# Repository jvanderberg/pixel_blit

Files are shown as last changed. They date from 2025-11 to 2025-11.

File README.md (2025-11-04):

# pixel_blit

A  32-channel addressable LED controller based on the Raspberry Pi RP2350B microcontroller.

## Overview

The pixel_blit is designed for controlling large-scale addressable LED installations. It features LVDS networking for daisy-chaining multiple controllers across long cable runs, making it ideal for large lighting installations.

## Key Specifications

- **Microcontroller**: Raspberry Pi RP2350B (QFN-80)
  - Dual Cortex-M33 cores @ 150 MHz
  - 8 PIO state machines for precise LED timing
  - USB High Speed (480 Mbps)

- **Output Channels**: 32 independent LED string outputs
  - 47Ω series resistors on all outputs
  - 3.3V to 5V level shifting
  - Screw terminal connections (3.5mm pitch)

- **Memory**:
  - 16MB QSPI Flash (W25Q128JVSIQTR)
  - MicroSD card slot for pattern storage

- **Power Management**:
  - 12V input via terminal blocks
  - TPS63070 buck-boost converter (12V → 5V, 2A)
  - ME6217C33 LDO regulator (5V → 3.3V, 300mA)

- **Networking**:
  - LVDS daisy-chaining via RJ45 connectors
  - 4-channel differential signaling (DSLVDS1047/1048)
  - 100Ω termination resistors
  - Supports long cable runs

- **User Interface**:
  - MicroSD card slot
  - 4 tactile buttons + 1 reset button
  - 4-position DIP switch
  - I2C display interface

## Board Details

- **PCB Size**: 175.5mm × 122.0mm
- **Layers**: 4-layer stackup (Signal/GND/Power/Signal)
- **Components**: 192 total (all SMT, single-sided assembly)
- **Connectors**:
  - 32× DB301V 3.5mm screw terminals (LED outputs)
  - 4× power input terminals (12V)
  - 2× RJ45 (LVDS networking)
  - 1× USB-C

## Architecture

### Signal Path
```
RP2350B GPIO (3.3V)
  → SN74LVC8T245 Level Shifter (4× 8-channel)
  → 47Ω Series Resistor
  → Screw Terminal
  → LED String
```

### Power Distribution
```
12V Input
  → TPS63070 Buck-Boost → 5V (LED outputs, level shifters)
  → ME6217C33 LDO → 3.3V (MCU, flash, LVDS)
  → RP2350B Internal → 1.1V
```

### Network Topology
```
[Controller 1] —RJ45→ Cat5/Cat6 —RJ45→ [Controller 2] —RJ45→ ...
```
LVDS differential signaling enables daisy-chaining multiple boards with deterministic latency and excellent noise immunity.

## Component Summary

| Type | Count | Examples |
|---|---|---|
| Resistors | 65 | 47Ω series resistors, 100Ω LVDS termination |
| Capacitors | 45 | Decoupling and power filtering |
| ICs | 50+ | MCU, flash, level shifters, LVDS transceivers |
| Terminal Blocks | 36 | 32 LED outputs + 4 power inputs |
| Level Shifters | 4 | SN74LVC8T245PWR (8-channel each) |
| Switches/Buttons | 5 | Tactile buttons + DIP switch |
| LVDS Transceivers | 2 | Driver and receiver pair |

## Features

- 32 independent addressable LED channels
- 800kHz data rate (WS2812B protocol)
- USB programming and control interface
- Offline pattern storage via MicroSD
- Long-distance networking via LVDS over Cat5/Cat6
- Complete user interface for standalone operation

## File Structure

```
pixel_blit/
├── pixel_blit.kicad_pcb      # Main PCB layout
├── pixel_blit.kicad_sch      # Top-level schematic
├── Power.kicad_sch           # Power management circuitry
├── output.kicad_sch          # LED output stage
├── communications.kicad_sch  # LVDS networking
├── peripherals.kicad_sch     # User interface components
├── Library.pretty/           # Custom footprints
└── production/               # Manufacturing outputs
```

## Manufacturing Notes

- All components on front side (single-sided assembly)
- 4-layer PCB with mixed signal/power routing
- 360 vias total
- Standard SMT assembly process

## Use Cases

- Architectural lighting installations
- Stage and entertainment lighting
- Large-scale pixel displays
- Holiday and decorative lighting
- Interactive art installations
- Any application requiring synchronized control of multiple LED strings over long distances

## License

MIT License

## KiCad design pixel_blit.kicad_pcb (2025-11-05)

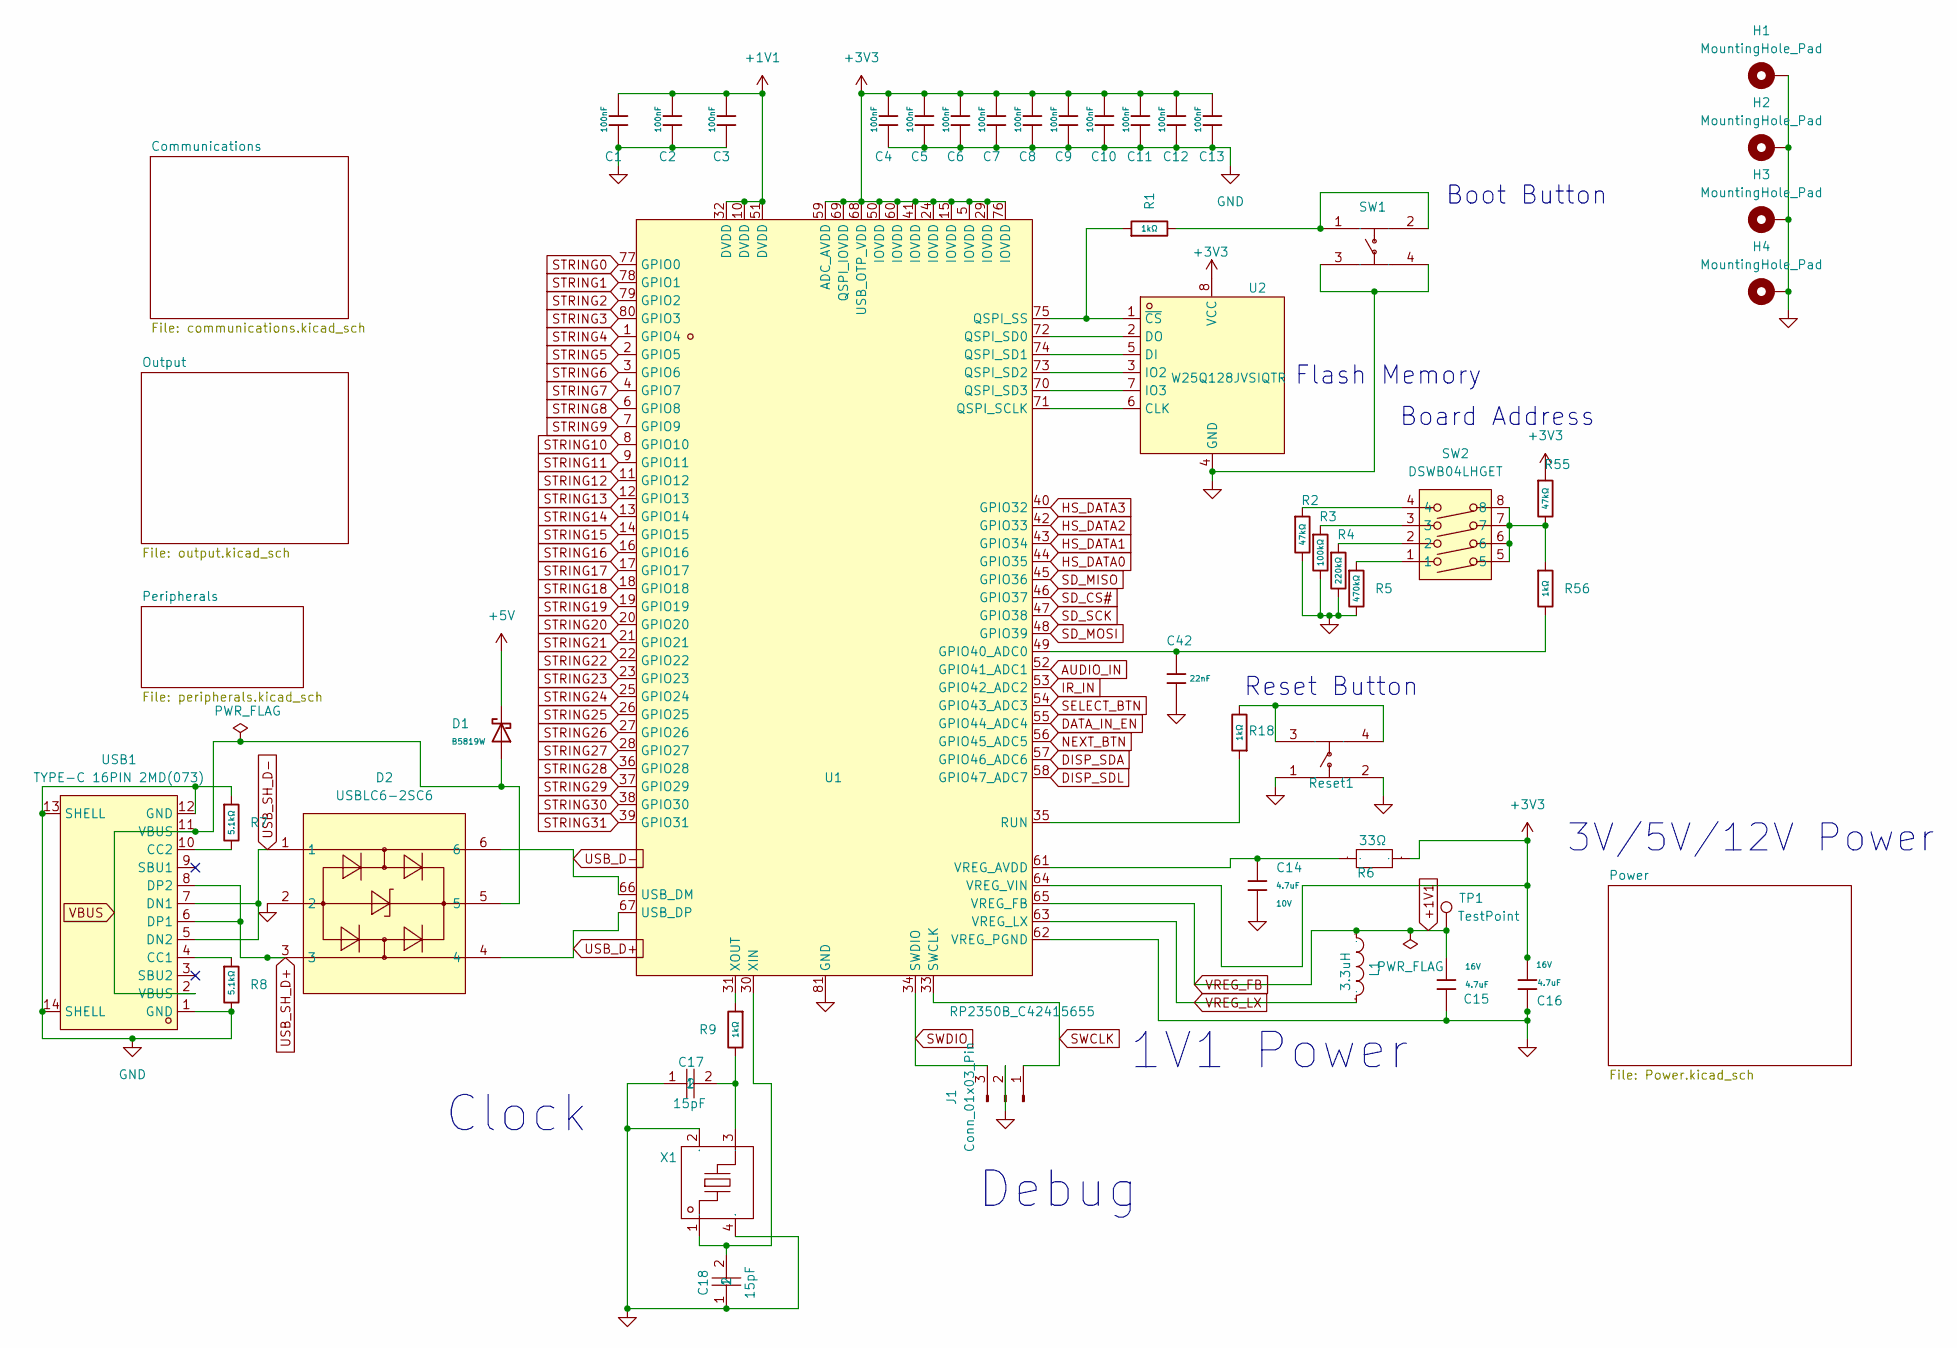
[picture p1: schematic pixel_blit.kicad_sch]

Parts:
C1, C2, C3, C4, C5, C6, C7, C8, C9, C10, C11, C12, C13: 100nF; C_0402; Voltage Rated 16V; Tolerance ±10%; Part CL05B104KO5NNNC; LCSC C1525
C14: 4.7uF; C_0402; Voltage Rated 10V; Tolerance ±20%; Part CL05A475MP5NRNC; LCSC C23733
C15, C16: 4.7uF; C_0603; Voltage Rated 16V; Tolerance ±10%; Part CL10A475KO8NNNC; LCSC C19666
C17, C18: 15pF; C0402; Manufacturer Part 0402CG150J500NT; LCSC Part Name 15pF ±5% 50V
C42: 22nF; C_0402; Voltage Rated 50V; Tolerance ±10%; Part 0402B223K500NT; LCSC C1532
D1: B5819W; D_SOD-123; Forward Voltage (Vf@If) 900mV@3A; Reverse Voltage (Vr) 40V; Part B5819W; LCSC C64885
D2: USBLC6-2SC6; SOT-23-6_L2.9-W1.6-P0.95-LS2.8-BL; LCSC Part C7519
H1, H2, H3, H4: MountingHole_Pad; MountingHole_3.2mm_M3_Pad_Via
J1: Conn_01x03_Pin; PinHeader_1x03_P2.54mm_Vertical
L1: IND-SMD_L2.0-W1.6_AOTA-B201610S3R3-101-T; Manufacturer Part AOTA-B201610S3R3-101-T; LCSC Part Name AOTA-B201610S3R3-101-T
R1, R18, R56: 1kΩ; R_0402; Overload Voltage (Max) 50V; Tolerance ±1%; Part 0402WGF1001TCE; LCSC C11702
R2, R55: 47kΩ; R_0402; Overload Voltage (Max) 50V; Tolerance ±1%; Part 0402WGF4702TCE; LCSC C25792
R3: 100kΩ; R_0402; Overload Voltage (Max) 50V; Tolerance ±1%; Part 0402WGF1003TCE; LCSC C25741
R4: 220kΩ; R_0402; Overload Voltage (Max) 50V; Tolerance ±1%; Part 0402WGF2203TCE; LCSC C25767
R5: 470kΩ; R_0402; Overload Voltage (Max) 50V; Tolerance ±1%; Part 0402WGF4703TCE; LCSC C25790
R6: 33Ω; R0402; Manufacturer Part 0402WGF330JTCE; LCSC Part Name 33Ω ±1% 62.5mW 厚膜电阻
R7, R8: 5.1kΩ; R_0402; Overload Voltage (Max) 50V; Tolerance ±1%; Part 0402WGF5101TCE; LCSC C25905
R9: 1kΩ; R_0603; Overload Voltage (Max) 75V; Tolerance ±1%; Part 0603WAF1001T5E; LCSC C21190
Reset1: K2-1808SN-A4SW-01; KEY-SMD_4P-L4.2-W3.2-P2.20-LS5.1-TL; Manufacturer Part K2-1808SN-A4SW-01; LCSC Part Name 4.2mm*3.25mm
SW1: K2-1808SN-A4SW; KEY-SMD_4P-L4.2-W3.2-P2.20-LS5.1-TL; LCSC Part C92589
SW2: DSWB04LHGET; SW-TH_DSWB04LHGET; LCSC Part C99418
TP1: TestPoint; TestPoint_Pad_1.0x1.0mm
U1: RP2350B_C42415655; QFN-80_L10.0-W10.0-P0.40-TL-EP3.4; LCSC Part C42415655
U2: W25Q128JVSIQTR; SOIC-8_L5.3-W5.3-P1.27-LS8.0-BL; LCSC Part C97521
USB1: TYPE-C 16PIN 2MD(073); USB-C-SMD_TYPE-C-6PIN-2MD-073; LCSC Part C2765186
X1: CRYSTAL-SMD_4P-L3.2-W2.5-BL; Manufacturer Part ABM8-272-T3; LCSC Part Name ABM8-272-T3

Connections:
+1V1: C1.1, C2.1, C3.1, C15.2, L1.2, TP1.1, U1.10 (DVDD), U1.32 (DVDD), U1.51 (DVDD), U1.65 (VREG_FB)
+3V3: C4.1, C5.1, C6.1, C7.1, C8.1, C9.1, C10.1, C11.1, C12.1, C13.1, C16.2, R6.1, R55.1, U1.5 (IOVDD), U1.15 (IOVDD), U1.24 (IOVDD), U1.29 (IOVDD), U1.41 (IOVDD), U1.50 (IOVDD), U1.59 (ADC_AVDD), U1.60 (IOVDD), U1.64 (VREG_VIN), U1.68 (USB_OTP_VDD), U1.69 (QSPI_IOVDD), U1.76 (IOVDD), U2.8 (VCC); also elsewhere on the board
+5V: D1.1; also elsewhere on the board
AUDIO_IN: U1.52 (GPIO41_ADC1); also elsewhere on the board
DATA_IN_EN: U1.55 (GPIO44_ADC4); also elsewhere on the board
DISP_SDA: U1.57 (GPIO46_ADC6); also elsewhere on the board
DISP_SDL: U1.58 (GPIO47_ADC7); also elsewhere on the board
GND: C1.2, C2.2, C3.2, C4.2, C5.2, C6.2, C7.2, C8.2, C9.2, C10.2, C11.2, C12.2, C13.2, C14.2, C15.1, C16.1, C17.1, C18.1, C42.2, D2.2, H1.1, H2.1, H3.1, H4.1, J1.2, R2.2, R3.2, R4.2, R5.2, R7.1, R8.2, Reset1.1, Reset1.2, SW1.3, SW1.4, U1.62 (VREG_PGND), U1.81 (GND), U2.4 (GND), USB1.1 (GND), USB1.12 (GND), USB1.13 (SHELL), USB1.14 (SHELL), X1.2 (GND), X1.4 (GND); also elsewhere on the board
HS_DATA0: U1.44 (GPIO35); also elsewhere on the board
HS_DATA1: U1.43 (GPIO34); also elsewhere on the board
HS_DATA2: U1.42 (GPIO33); also elsewhere on the board
HS_DATA3: U1.40 (GPIO32); also elsewhere on the board
IR_IN: U1.53 (GPIO42_ADC2); also elsewhere on the board
NEXT_BTN: U1.56 (GPIO45_ADC5); also elsewhere on the board
unnamed: C17.2, R9.2, X1.3
unnamed: R1.2, SW1.1, SW1.2
unnamed: R2.1, SW2.4
unnamed: R3.1, SW2.3
unnamed: R4.1, SW2.2
unnamed: R5.1, SW2.1
unnamed: R18.2, Reset1.3, Reset1.4
unnamed: R55.2, R56.1, SW2.5, SW2.6, SW2.7, SW2.8
unnamed: C42.1, R56.2, U1.49 (GPIO40_ADC0)
unnamed: U1.71 (QSPI_SCLK), U2.6 (CLK)
unnamed: U1.72 (QSPI_SD0), U2.2 (DO)
unnamed: U1.74 (QSPI_SD1), U2.5 (DI)
unnamed: U1.73 (QSPI_SD2), U2.3 (IO2)
unnamed: U1.70 (QSPI_SD3), U2.7 (IO3)
unnamed: R1.1, U1.75 (QSPI_SS), U2.1 (~CS)
unnamed: R18.1, U1.35 (RUN)
unnamed: C14.1, R6.2, U1.61 (VREG_AVDD)
unnamed: C18.2, U1.30 (XIN), X1.1
unnamed: R9.1, U1.31 (XOUT)
unnamed: R8.1, USB1.4 (CC1)
unnamed: R7.2, USB1.10 (CC2)
SD_CS#: U1.46 (GPIO37); also elsewhere on the board
SD_MISO: U1.45 (GPIO36); also elsewhere on the board
SD_MOSI: U1.48 (GPIO39); also elsewhere on the board
SD_SCK: U1.47 (GPIO38); also elsewhere on the board
SELECT_BTN: U1.54 (GPIO43_ADC3); also elsewhere on the board
STRING0: U1.77 (GPIO0); also elsewhere on the board
STRING1: U1.78 (GPIO1); also elsewhere on the board
STRING2: U1.79 (GPIO2); also elsewhere on the board
STRING3: U1.80 (GPIO3); also elsewhere on the board
STRING4: U1.1 (GPIO4); also elsewhere on the board
STRING5: U1.2 (GPIO5); also elsewhere on the board
STRING6: U1.3 (GPIO6); also elsewhere on the board
STRING7: U1.4 (GPIO7); also elsewhere on the board
STRING8: U1.6 (GPIO8); also elsewhere on the board
STRING9: U1.7 (GPIO9); also elsewhere on the board
STRING10: U1.8 (GPIO10); also elsewhere on the board
STRING11: U1.9 (GPIO11); also elsewhere on the board
STRING12: U1.11 (GPIO12); also elsewhere on the board
STRING13: U1.12 (GPIO13); also elsewhere on the board
STRING14: U1.13 (GPIO14); also elsewhere on the board
STRING15: U1.14 (GPIO15); also elsewhere on the board
STRING16: U1.16 (GPIO16); also elsewhere on the board
STRING17: U1.17 (GPIO17); also elsewhere on the board
STRING18: U1.18 (GPIO18); also elsewhere on the board
STRING19: U1.19 (GPIO19); also elsewhere on the board
STRING20: U1.20 (GPIO20); also elsewhere on the board
STRING21: U1.21 (GPIO21); also elsewhere on the board
STRING22: U1.22 (GPIO22); also elsewhere on the board
STRING23: U1.23 (GPIO23); also elsewhere on the board
STRING24: U1.25 (GPIO24); also elsewhere on the board
STRING25: U1.26 (GPIO25); also elsewhere on the board
STRING26: U1.27 (GPIO26); also elsewhere on the board
STRING27: U1.28 (GPIO27); also elsewhere on the board
STRING28: U1.36 (GPIO28); also elsewhere on the board
STRING29: U1.37 (GPIO29); also elsewhere on the board
STRING30: U1.38 (GPIO30); also elsewhere on the board
STRING31: U1.39 (GPIO31); also elsewhere on the board
SWCLK: J1.1, U1.33 (SWCLK)
SWDIO: J1.3, U1.34 (SWDIO)
USB_D+: D2.4, U1.67 (USB_DP)
USB_D-: D2.6, U1.66 (USB_DM)
USB_SH_D+: D2.3, USB1.6 (DP1), USB1.8 (DP2)
USB_SH_D-: D2.1, USB1.5 (DN2), USB1.7 (DN1)
VBUS: D1.2, D2.5, USB1.2 (VBUS), USB1.11 (VBUS)
VREG_LX: L1.1, U1.63 (VREG_LX)

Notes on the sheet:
Reset Button
Debug
Board Address
Boot Button
Clock
3V/5V/12V Power
Flash Memory
1V1 Power

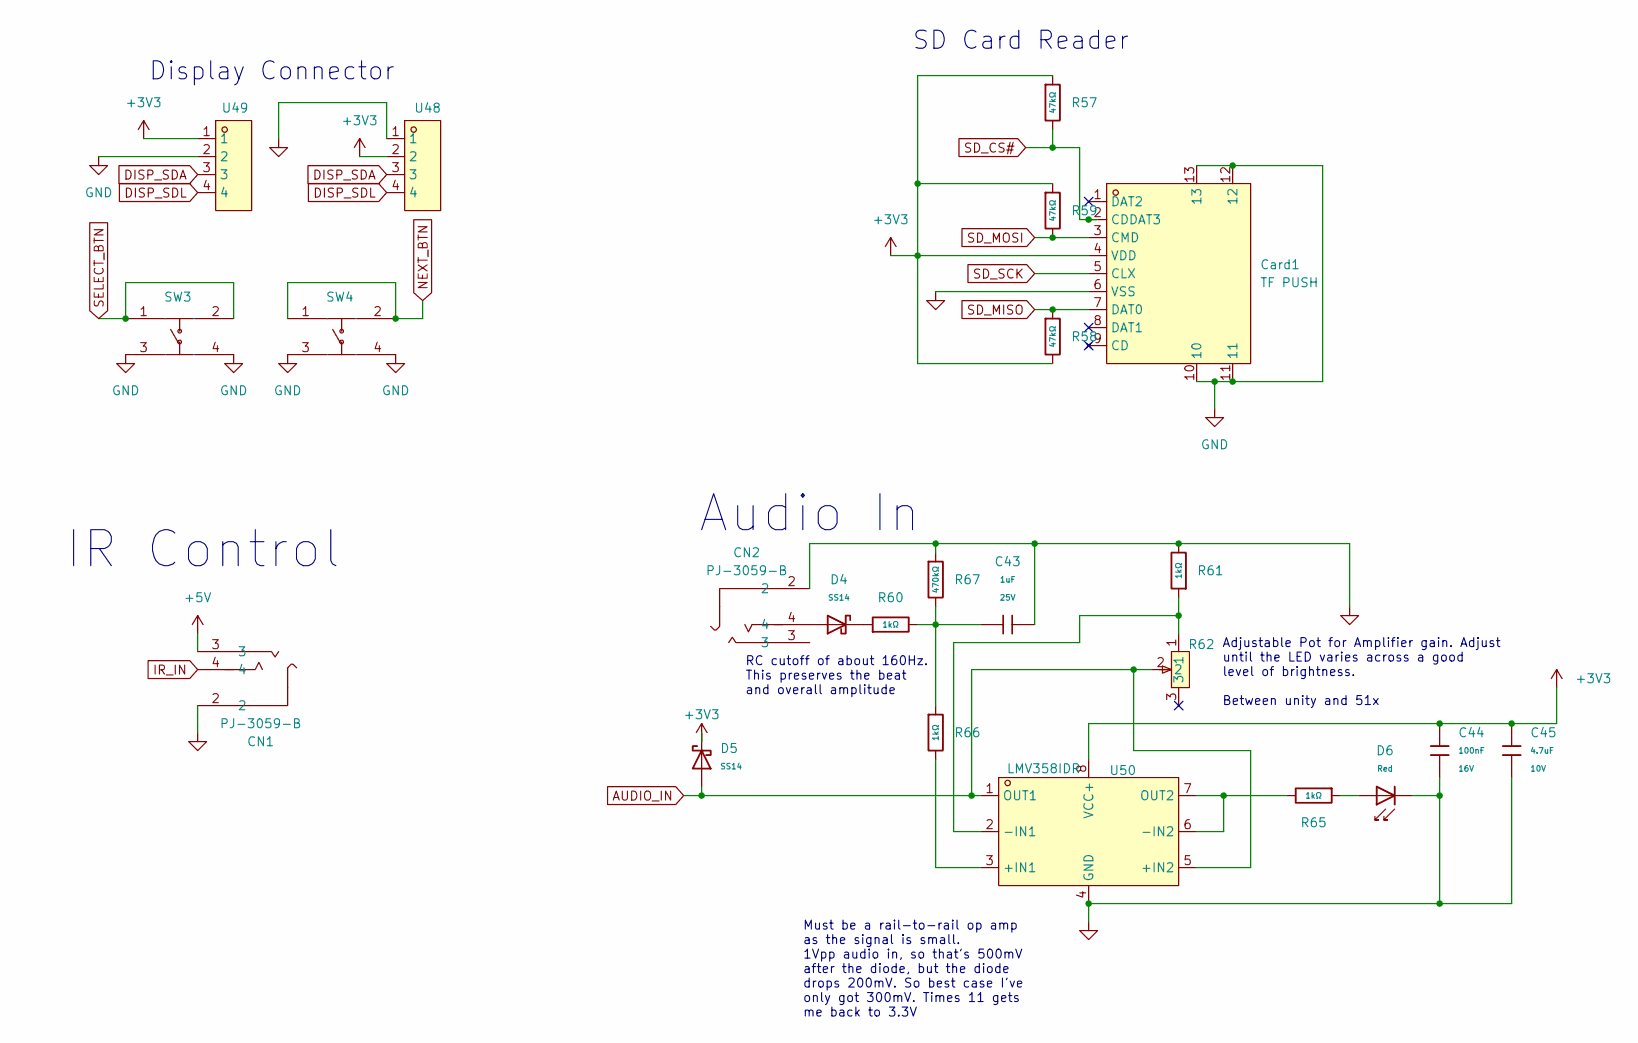
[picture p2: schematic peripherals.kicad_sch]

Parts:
C43: 1uF; C_0402; Voltage Rated 25V; Tolerance ±10%; Part CL05A105KA5NQNC; LCSC C52923
C44: 100nF; C_0402; Voltage Rated 16V; Tolerance ±10%; Part CL05B104KO5NNNC; LCSC C1525
C45: 4.7uF; C_0402; Voltage Rated 10V; Tolerance ±20%; Part CL05A475MP5NRNC; LCSC C23733
CN1, CN2: PJ-3059-B; AUDIO-TH_XKB_PJ-3059-B; LCSC Part C2884976
Card1: TF PUSH; TF-SMD_TF-PUSH; LCSC Part C393941
D4, D5: SS14; D_SMA; Forward Voltage (Vf@If) 550mV@1A; Reverse Voltage (Vr) 40V; Part SS14; LCSC C2480
D6: Red; D_0603; Part KT-0603R; LCSC C2286
R57, R58, R59: 47kΩ; R_0402; Overload Voltage (Max) 50V; Tolerance ±1%; Part 0402WGF4702TCE; LCSC C25792
R60, R61: 1kΩ; R_0603; Overload Voltage (Max) 75V; Tolerance ±1%; Part 0603WAF1001T5E; LCSC C21190
R62: 3362P-1-503LF; RES-ADJ-TH_3362P; LCSC Part C81264
R65, R66: 1kΩ; R_0402; Overload Voltage (Max) 50V; Tolerance ±1%; Part 0402WGF1001TCE; LCSC C11702
R67: 470kΩ; R_0402; Overload Voltage (Max) 50V; Tolerance ±1%; Part 0402WGF4703TCE; LCSC C25790
SW3, SW4: K2-1808SN-A4SW; KEY-SMD_4P-L4.2-W3.2-P2.20-LS5.1-TL; LCSC Part C92589
U48, U49: 2.54-1*4; HDR-TH_4P-P2.54-V-M-1; LCSC Part C5116483
U50: LMV358IDR; SOIC-8_L4.9-W3.9-P1.27-LS6.0-BL; LCSC Part C63813

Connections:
+3V3: C44.1, C45.1, Card1.4 (VDD), D5.1, R57.1, R58.2, R59.1, U48.2, U49.1, U50.8 (VCC+); also elsewhere on the board
+5V: CN1.3; also elsewhere on the board
AUDIO_IN: D5.2, R62.2, U50.1 (OUT1), U50.5 (+IN2); also elsewhere on the board
DISP_SDA: U48.3, U49.3; also elsewhere on the board
DISP_SDL: U48.4, U49.4; also elsewhere on the board
GND: C43.2, C44.2, C45.2, CN1.2, CN2.2, Card1.6 (VSS), Card1.10, Card1.11, Card1.12, Card1.13, D6.1, R61.2, R67.1, SW3.3, SW3.4, SW4.3, SW4.4, U48.1, U49.2, U50.4 (GND); also elsewhere on the board
IR_IN: CN1.4; also elsewhere on the board
NEXT_BTN: SW4.1, SW4.2; also elsewhere on the board
unnamed: C43.1, R60.2, R66.1, R67.2
unnamed: CN2.4, D4.2
unnamed: D4.1, R60.1
unnamed: D6.2, R65.1
unnamed: R66.2, U50.3 (+IN1)
unnamed: R61.1, R62.1, U50.2 (-IN1)
unnamed: R65.2, U50.6 (-IN2), U50.7 (OUT2)
SD_CS#: Card1.2 (CDDAT3), R57.2; also elsewhere on the board
SD_MISO: Card1.7 (DAT0), R58.1; also elsewhere on the board
SD_MOSI: Card1.3 (CMD), R59.2; also elsewhere on the board
SD_SCK: Card1.5 (CLX); also elsewhere on the board
SELECT_BTN: SW3.1, SW3.2; also elsewhere on the board

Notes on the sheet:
Display Connector
Adjustable Pot for Amplifier gain. Adjust until the LED varies across a good level of brightness. Between unity and 51x
Must be a rail-to-rail op amp as the signal is small. 1Vpp audio in, so that's 500mV after the diode, but the diode drops 200mV. So best case I've only got 300mV. Times 11 gets me back to 3.3V
IR Control
Audio In
SD Card Reader
RC cutoff of about 160Hz. This preserves the beat and overall amplitude

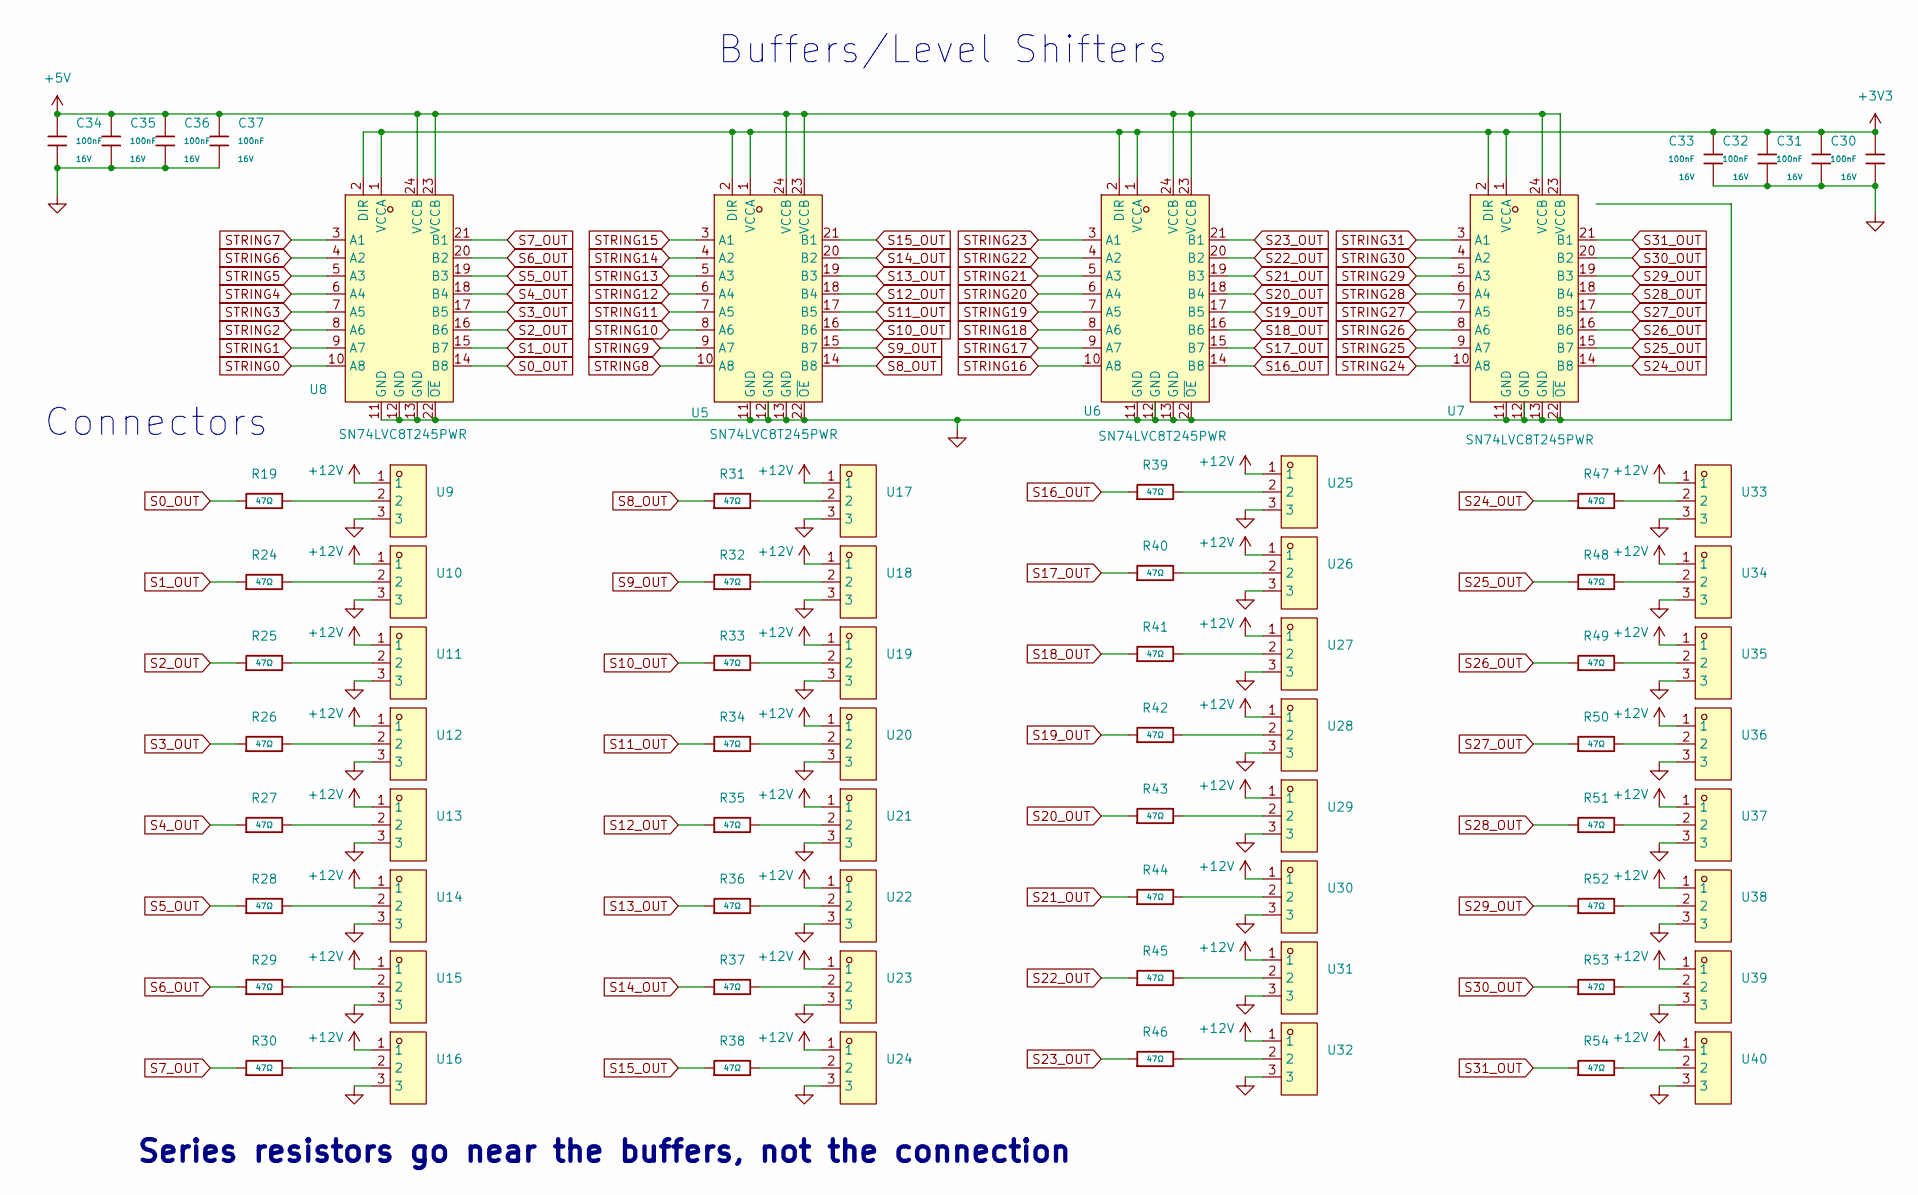
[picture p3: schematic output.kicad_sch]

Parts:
C30, C31, C32, C33, C34, C35, C36, C37: 100nF; C_0402; Voltage Rated 16V; Tolerance ±10%; Part CL05B104KO5NNNC; LCSC C1525
R19, R24, R25, R26, R27, R28, R29, R30, R31, R32, R33, R34, R35, R36, R37, R38, R39, R40, R41, R42, R43, R44, R45, R46, R47, R48, R49, R50, R51, R52, R53, R54: 47Ω; R_0402; Overload Voltage (Max) 50V; Tolerance ±1%; Part 0402WGF470JTCE; LCSC C25118
U5, U6, U7, U8: SN74LVC8T245PWR; TSSOP-24_L7.8-W4.4-P0.65-LS6.4-BL; LCSC Part C27643
U9, U10, U11, U12, U13, U14, U15, U16, U17, U18, U19, U20, U21, U22, U23, U24, U25, U26, U27, U28, U29, U30, U31, U32, U33, U34, U35, U36, U37, U38, U39, U40: DB301V-3.5-3P-GN; CONN-TH_DB301V-3.5-3P-GN; LCSC Part C695630

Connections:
+3V3: C30.1, C31.1, C32.1, C33.1, U5.1 (VCCA), U5.2 (DIR), U6.1 (VCCA), U6.2 (DIR), U7.1 (VCCA), U7.2 (DIR), U8.1 (VCCA), U8.2 (DIR); also elsewhere on the board
+5V: C34.1, C35.1, C36.1, C37.1, U5.23 (VCCB), U5.24 (VCCB), U6.23 (VCCB), U6.24 (VCCB), U7.23 (VCCB), U7.24 (VCCB), U8.23 (VCCB), U8.24 (VCCB); also elsewhere on the board
+12V: U9.1, U10.1, U11.1, U12.1, U13.1, U14.1, U15.1, U16.1, U17.1, U18.1, U19.1, U20.1, U21.1, U22.1, U23.1, U24.1, U25.1, U26.1, U27.1, U28.1, U29.1, U30.1, U31.1, U32.1, U33.1, U34.1, U35.1, U36.1, U37.1, U38.1, U39.1, U40.1; also elsewhere on the board
GND: C30.2, C31.2, C32.2, C33.2, C34.2, C35.2, C36.2, C37.2, U5.11 (GND), U5.12 (GND), U5.13 (GND), U5.22 (~OE), U6.11 (GND), U6.12 (GND), U6.13 (GND), U6.22 (~OE), U7.11 (GND), U7.12 (GND), U7.13 (GND), U7.22 (~OE), U8.11 (GND), U8.12 (GND), U8.13 (GND), U8.22 (~OE), U9.3, U10.3, U11.3, U12.3, U13.3, U14.3, U15.3, U16.3, U17.3, U18.3, U19.3, U20.3, U21.3, U22.3, U23.3, U24.3, U25.3, U26.3, U27.3, U28.3, U29.3, U30.3, U31.3, U32.3, U33.3, U34.3, U35.3, U36.3, U37.3, U38.3, U39.3, U40.3; also elsewhere on the board
unnamed: R19.2, U9.2
unnamed: R24.2, U10.2
unnamed: R25.2, U11.2
unnamed: R26.2, U12.2
unnamed: R27.2, U13.2
unnamed: R28.2, U14.2
unnamed: R29.2, U15.2
unnamed: R30.2, U16.2
unnamed: R31.2, U17.2
unnamed: R32.2, U18.2
unnamed: R33.2, U19.2
unnamed: R34.2, U20.2
unnamed: R35.2, U21.2
unnamed: R36.2, U22.2
unnamed: R37.2, U23.2
unnamed: R38.2, U24.2
unnamed: R39.2, U25.2
unnamed: R40.2, U26.2
unnamed: R41.2, U27.2
unnamed: R42.2, U28.2
unnamed: R43.2, U29.2
unnamed: R44.2, U30.2
unnamed: R45.2, U31.2
unnamed: R46.2, U32.2
unnamed: R47.2, U33.2
unnamed: R48.2, U34.2
unnamed: R49.2, U35.2
unnamed: R50.2, U36.2
unnamed: R51.2, U37.2
unnamed: R52.2, U38.2
unnamed: R53.2, U39.2
unnamed: R54.2, U40.2
S0_OUT: R19.1, U8.14 (B8)
S1_OUT: R24.1, U8.15 (B7)
S2_OUT: R25.1, U8.16 (B6)
S3_OUT: R26.1, U8.17 (B5)
S4_OUT: R27.1, U8.18 (B4)
S5_OUT: R28.1, U8.19 (B3)
S6_OUT: R29.1, U8.20 (B2)
S7_OUT: R30.1, U8.21 (B1)
S8_OUT: R31.1, U5.14 (B8)
S9_OUT: R32.1, U5.15 (B7)
S10_OUT: R33.1, U5.16 (B6)
S11_OUT: R34.1, U5.17 (B5)
S12_OUT: R35.1, U5.18 (B4)
S13_OUT: R36.1, U5.19 (B3)
S14_OUT: R37.1, U5.20 (B2)
S15_OUT: R38.1, U5.21 (B1)
S16_OUT: R39.1, U6.14 (B8)
S17_OUT: R40.1, U6.15 (B7)
S18_OUT: R41.1, U6.16 (B6)
S19_OUT: R42.1, U6.17 (B5)
S20_OUT: R43.1, U6.18 (B4)
S21_OUT: R44.1, U6.19 (B3)
S22_OUT: R45.1, U6.20 (B2)
S23_OUT: R46.1, U6.21 (B1)
S24_OUT: R47.1, U7.14 (B8)
S25_OUT: R48.1, U7.15 (B7)
S26_OUT: R49.1, U7.16 (B6)
S27_OUT: R50.1, U7.17 (B5)
S28_OUT: R51.1, U7.18 (B4)
S29_OUT: R52.1, U7.19 (B3)
S30_OUT: R53.1, U7.20 (B2)
S31_OUT: R54.1, U7.21 (B1)
STRING0: U8.10 (A8); also elsewhere on the board
STRING1: U8.9 (A7); also elsewhere on the board
STRING2: U8.8 (A6); also elsewhere on the board
STRING3: U8.7 (A5); also elsewhere on the board
STRING4: U8.6 (A4); also elsewhere on the board
STRING5: U8.5 (A3); also elsewhere on the board
STRING6: U8.4 (A2); also elsewhere on the board
STRING7: U8.3 (A1); also elsewhere on the board
STRING8: U5.10 (A8); also elsewhere on the board
STRING9: U5.9 (A7); also elsewhere on the board
STRING10: U5.8 (A6); also elsewhere on the board
STRING11: U5.7 (A5); also elsewhere on the board
STRING12: U5.6 (A4); also elsewhere on the board
STRING13: U5.5 (A3); also elsewhere on the board
STRING14: U5.4 (A2); also elsewhere on the board
STRING15: U5.3 (A1); also elsewhere on the board
STRING16: U6.10 (A8); also elsewhere on the board
STRING17: U6.9 (A7); also elsewhere on the board
STRING18: U6.8 (A6); also elsewhere on the board
STRING19: U6.7 (A5); also elsewhere on the board
STRING20: U6.6 (A4); also elsewhere on the board
STRING21: U6.5 (A3); also elsewhere on the board
STRING22: U6.4 (A2); also elsewhere on the board
STRING23: U6.3 (A1); also elsewhere on the board
STRING24: U7.10 (A8); also elsewhere on the board
STRING25: U7.9 (A7); also elsewhere on the board
STRING26: U7.8 (A6); also elsewhere on the board
STRING27: U7.7 (A5); also elsewhere on the board
STRING28: U7.6 (A4); also elsewhere on the board
STRING29: U7.5 (A3); also elsewhere on the board
STRING30: U7.4 (A2); also elsewhere on the board
STRING31: U7.3 (A1); also elsewhere on the board

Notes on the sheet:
Buffers/Level Shifters
Connectors
Series resistors go near the buffers, not the connection

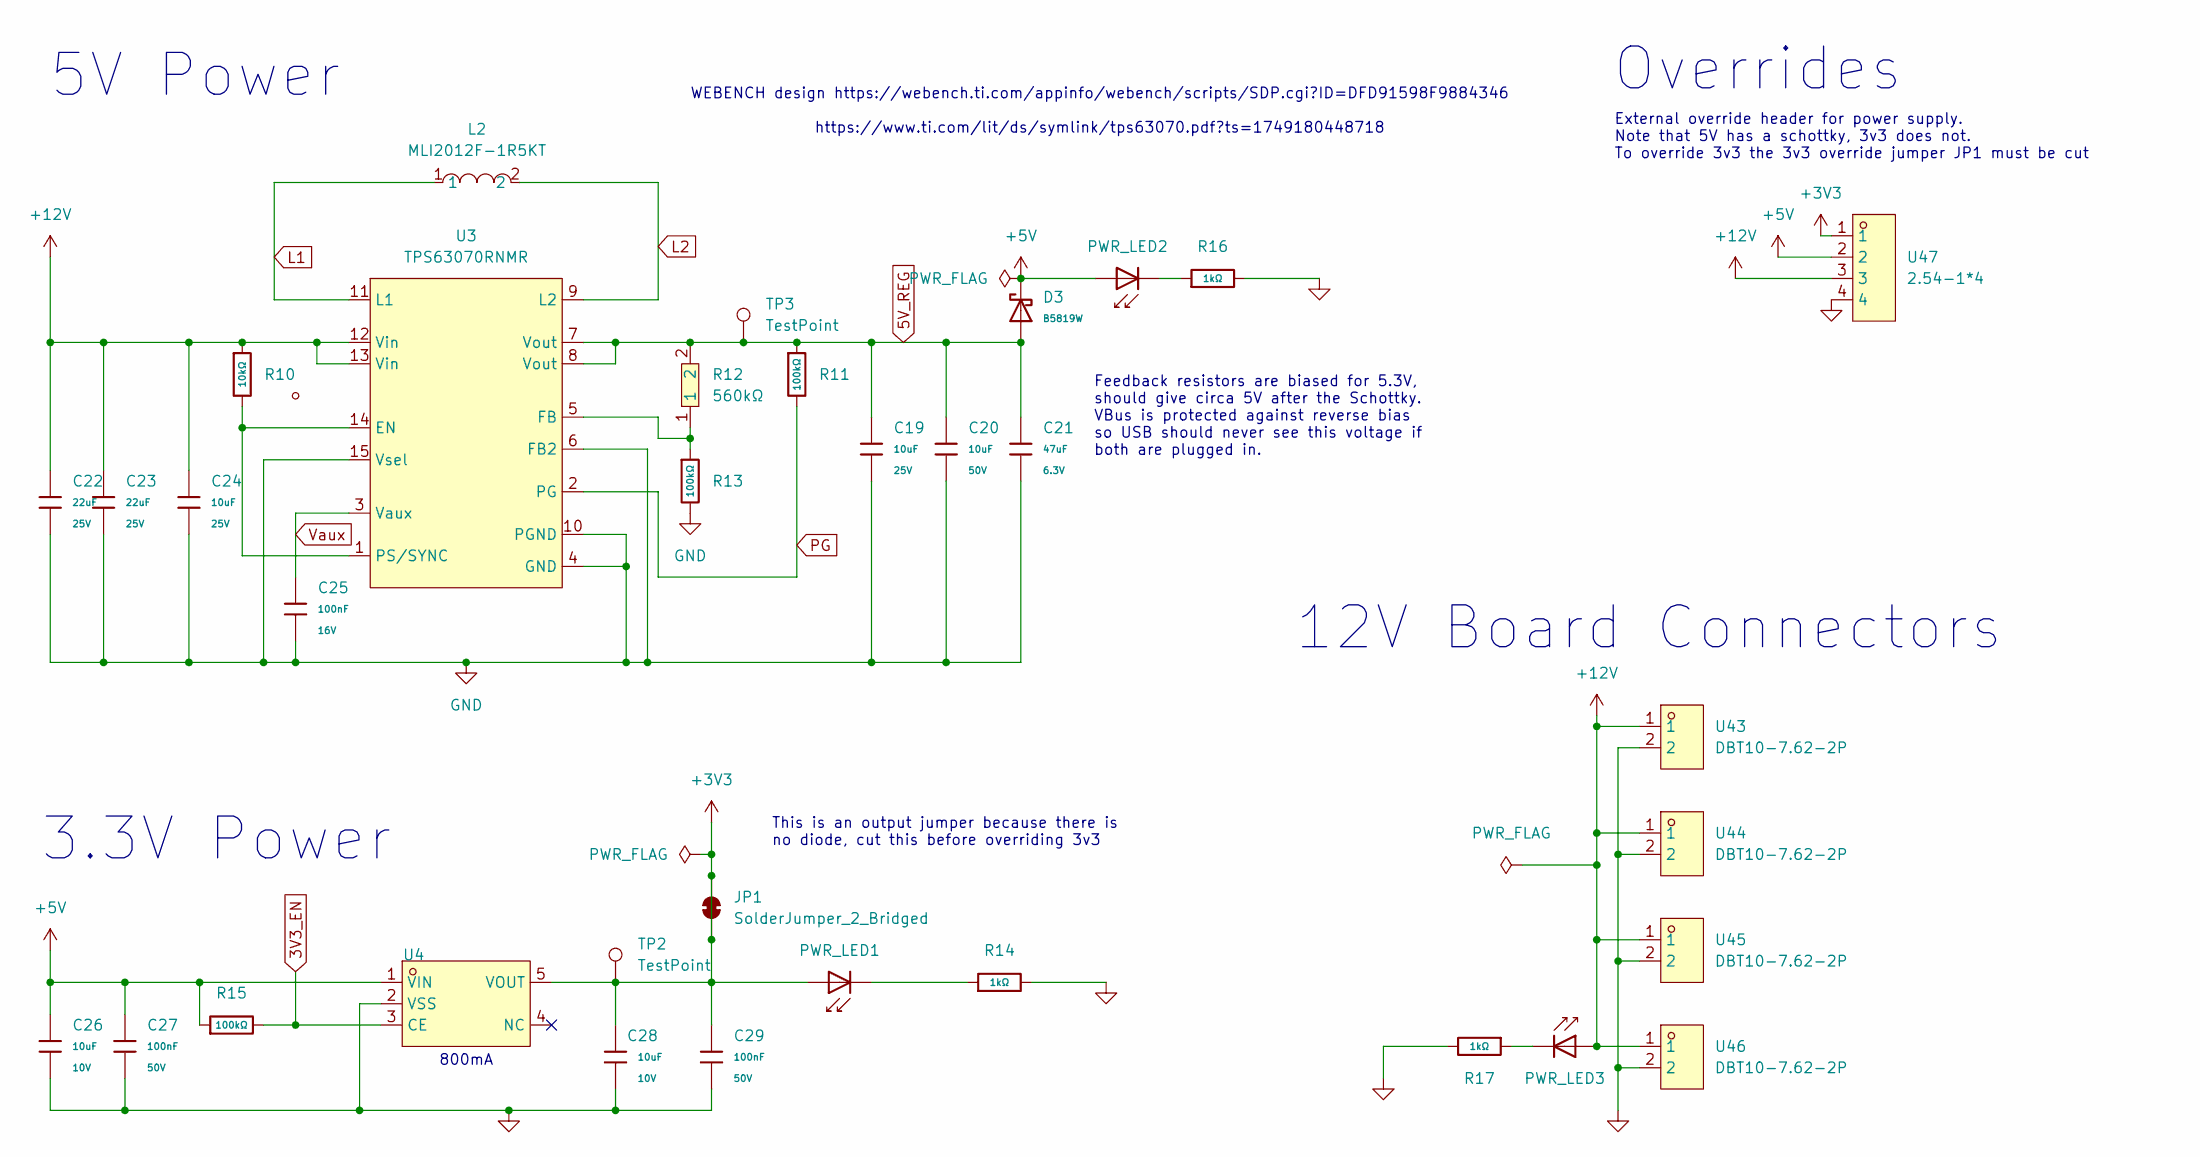
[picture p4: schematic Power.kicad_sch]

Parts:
C19, C24: 10uF; C_0603; Voltage Rated 25V; Tolerance ±20%; Part CL10A106MA8NRNC; LCSC C96446
C20: 10uF; C_0805; Voltage Rated 50V; Tolerance ±10%; Part GRM21BR61H106KE43L; LCSC C440198
C21: 47uF; C_0805; Voltage Rated 6.3V; Tolerance ±20%; Part CL21A476MQYNNNE; LCSC C16780
C22, C23: 22uF; C_0805; Voltage Rated 25V; Tolerance ±20%; Part CL21A226MAQNNNE; LCSC C45783
C25: 100nF; C_0402; Voltage Rated 16V; Tolerance ±10%; Part CL05B104KO5NNNC; LCSC C1525
C26, C28: 10uF; C_0603; Voltage Rated 10V; Tolerance ±10%; Part CL10A106KP8NNNC; LCSC C19702
C27, C29: 100nF; C_0603; Voltage Rated 50V; Tolerance ±10%; Part CC0603KRX7R9BB104; LCSC C14663
D3: B5819W; D_SOD-123; Forward Voltage (Vf@If) 900mV@3A; Reverse Voltage (Vr) 40V; Part B5819W; LCSC C64885
JP1: SolderJumper_2_Bridged
L2: MLI2012F-1R5KT; L0805; LCSC Part C2885888
PWR_LED1, PWR_LED2, PWR_LED3: Red; D_0603; Part KT-0603R; LCSC C2286
R10: 10kΩ; R_0603; Overload Voltage (Max) 75V; Tolerance ±1%; Part 0603WAF1002T5E; LCSC C25804
R11, R13: 100kΩ; R_0603; Overload Voltage (Max) 75V; Tolerance ±1%; Part 0603WAF1003T5E; LCSC C25803
R12: 560kΩ; R0402; LCSC Part C132339
R14, R16, R17: 1kΩ; R_0402; Overload Voltage (Max) 50V; Tolerance ±1%; Part 0402WGF1001TCE; LCSC C11702
R15: 100kΩ; R_0402; Overload Voltage (Max) 50V; Tolerance ±1%; Part 0402WGF1003TCE; LCSC C25741
TP2, TP3: TestPoint; TestPoint_Pad_1.0x1.0mm
U3: TPS63070RNMR; VQFN-HR-15_L3.0-W2.5-P0.50-BL_TPS63070RNMR; LCSC Part C109322
U4: SOT-23-5_L3.0-W1.7-P0.95-LS2.8-BR; Manufacturer Part ME6217C33M5G; LCSC Part Name ME6217C33M5G
U43, U44, U45, U46: DBT10-7.62-2P; CONN-TH_2P-P7.62_DBT10-7.62-2P; LCSC Part C395930
U47: 2.54-1*4; HDR-TH_4P-P2.54-V-M-1; LCSC Part C5116483

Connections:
3V3_EN: R15.2, U4.3 (CE)
5V_REG: C19.1, C20.1, C21.1, D3.2, R11.1, R12.2, TP3.1, U3.7 (Vout), U3.8 (Vout)
+3V3: C28.1, C29.1, JP1.1 (A), JP1.2 (B), PWR_LED1.2, TP2.1, U4.5 (VOUT), U47.1; also elsewhere on the board
+5V: C26.1, C27.1, D3.1, PWR_LED2.2, R15.1, U4.1 (VIN), U47.2; also elsewhere on the board
+12V: C22.1, C23.1, C24.1, PWR_LED3.2, R10.1, U3.12 (Vin), U3.13 (Vin), U43.1, U44.1, U45.1, U46.1, U47.3; also elsewhere on the board
GND: C19.2, C20.2, C21.2, C22.2, C23.2, C24.2, C25.2, C26.2, C27.2, C28.2, C29.2, R13.2, R14.2, R16.2, R17.2, U3.4 (GND), U3.6 (FB2), U3.10 (PGND), U3.15 (Vsel), U4.2 (VSS), U43.2, U44.2, U45.2, U46.2, U47.4; also elsewhere on the board
L1: L2.1, U3.11 (L1)
L2: L2.2, U3.9 (L2)
unnamed: PWR_LED1.1, R14.1
unnamed: PWR_LED2.1, R16.1
unnamed: PWR_LED3.1, R17.1
unnamed: R10.2, U3.1 (PS/SYNC), U3.14 (EN)
unnamed: R12.1, R13.1, U3.5 (FB)
PG: R11.2, U3.2 (PG)
Vaux: C25.1, U3.3 (Vaux)

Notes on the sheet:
External override header for power supply. Note that 5V has a schottky, 3v3 does not. To override 3v3 the 3v3 override jumper JP1 must be cut
3.3V Power
Feedback resistors are biased for 5.3V, should give circa 5V after the Schottky. VBus is protected against reverse bias so USB should never see this voltage if both are plugged in.
Overrides
WEBENCH design https://webench.ti.com/appinfo/webench/scripts/SDP.cgi?ID=DFD91598F9884346 https://www.ti.com/lit/ds/symlink/tps63070.pdf?ts=1749180448718
800mA
This is an output jumper because there is no diode, cut this before overriding 3v3
12V Board Connectors
5V Power

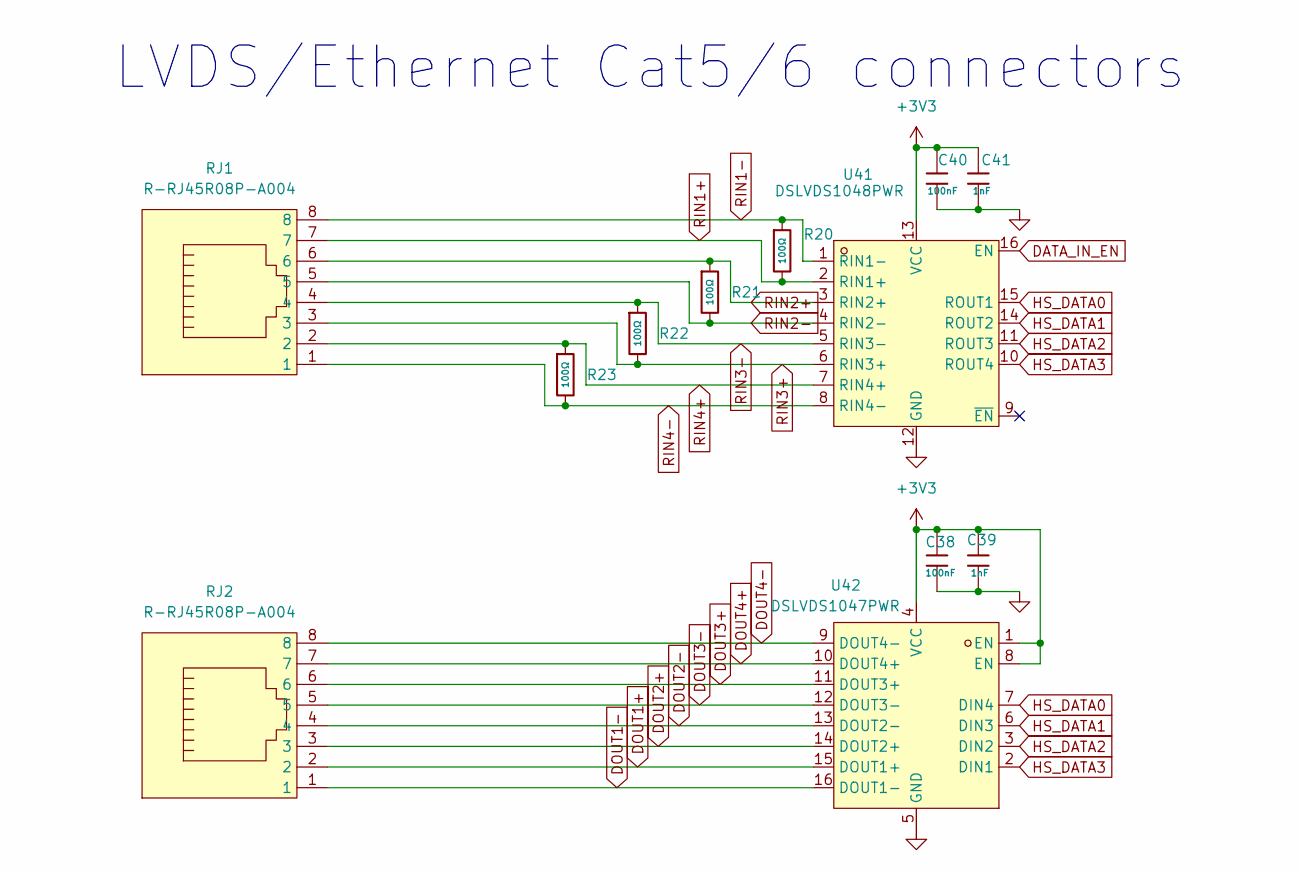
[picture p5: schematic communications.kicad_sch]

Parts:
C38, C40: 100nF; C_0402; Voltage Rated 16V; Tolerance ±10%; Part CL05B104KO5NNNC; LCSC C1525
C39, C41: 1nF; C_0402; Voltage Rated 50V; Tolerance ±10%; Part 0402B102K500NT; LCSC C1523
R20, R21, R22, R23: 100Ω; R_0402; Overload Voltage (Max) 50V; Tolerance ±1%; Part 0402WGF1000TCE; LCSC C25076
RJ1, RJ2: R-RJ45R08P-A004; RJ45-TH_R-RJ45R08P-A004; LCSC Part C385834
U41: DSLVDS1048PWR; TSSOP-16_L5.0-W4.4-P0.65-LS6.4-BL; LCSC Part C2671655
U42: DSLVDS1047PWR; TSSOP-16_L5.0-W4.4-P0.65-LS6.4-TL; LCSC Part C2671205

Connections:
+3V3: C38.1, C39.1, C40.1, C41.1, U41.13 (VCC), U42.1 (EN), U42.4 (VCC), U42.8 (EN); also elsewhere on the board
DATA_IN_EN: U41.16 (EN); also elsewhere on the board
DOUT1+: RJ2.2, U42.15 (DOUT1+)
DOUT1-: RJ2.1, U42.16 (DOUT1-)
DOUT2+: RJ2.3, U42.14 (DOUT2+)
DOUT2-: RJ2.4, U42.13 (DOUT2-)
DOUT3+: RJ2.6, U42.11 (DOUT3+)
DOUT3-: RJ2.5, U42.12 (DOUT3-)
DOUT4+: RJ2.7, U42.10 (DOUT4+)
DOUT4-: RJ2.8, U42.9 (DOUT4-)
GND: C38.2, C39.2, C40.2, C41.2, U41.12 (GND), U42.5 (GND); also elsewhere on the board
HS_DATA0: U41.15 (ROUT1), U42.7 (DIN4); also elsewhere on the board
HS_DATA1: U41.14 (ROUT2), U42.6 (DIN3); also elsewhere on the board
HS_DATA2: U41.11 (ROUT3), U42.3 (DIN2); also elsewhere on the board
HS_DATA3: U41.10 (ROUT4), U42.2 (DIN1); also elsewhere on the board
RIN1+: R20.2, RJ1.7, U41.2 (RIN1+)
RIN1-: R20.1, RJ1.8, U41.1 (RIN1-)
RIN2+: R21.1, RJ1.6, U41.3 (RIN2+)
RIN2-: R21.2, RJ1.5, U41.4 (RIN2-)
RIN3+: R22.2, RJ1.3, U41.6 (RIN3+)
RIN3-: R22.1, RJ1.4, U41.5 (RIN3-)
RIN4+: R23.1, RJ1.2, U41.7 (RIN4+)
RIN4-: R23.2, RJ1.1, U41.8 (RIN4-)

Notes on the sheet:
LVDS/Ethernet Cat5/6 connectors

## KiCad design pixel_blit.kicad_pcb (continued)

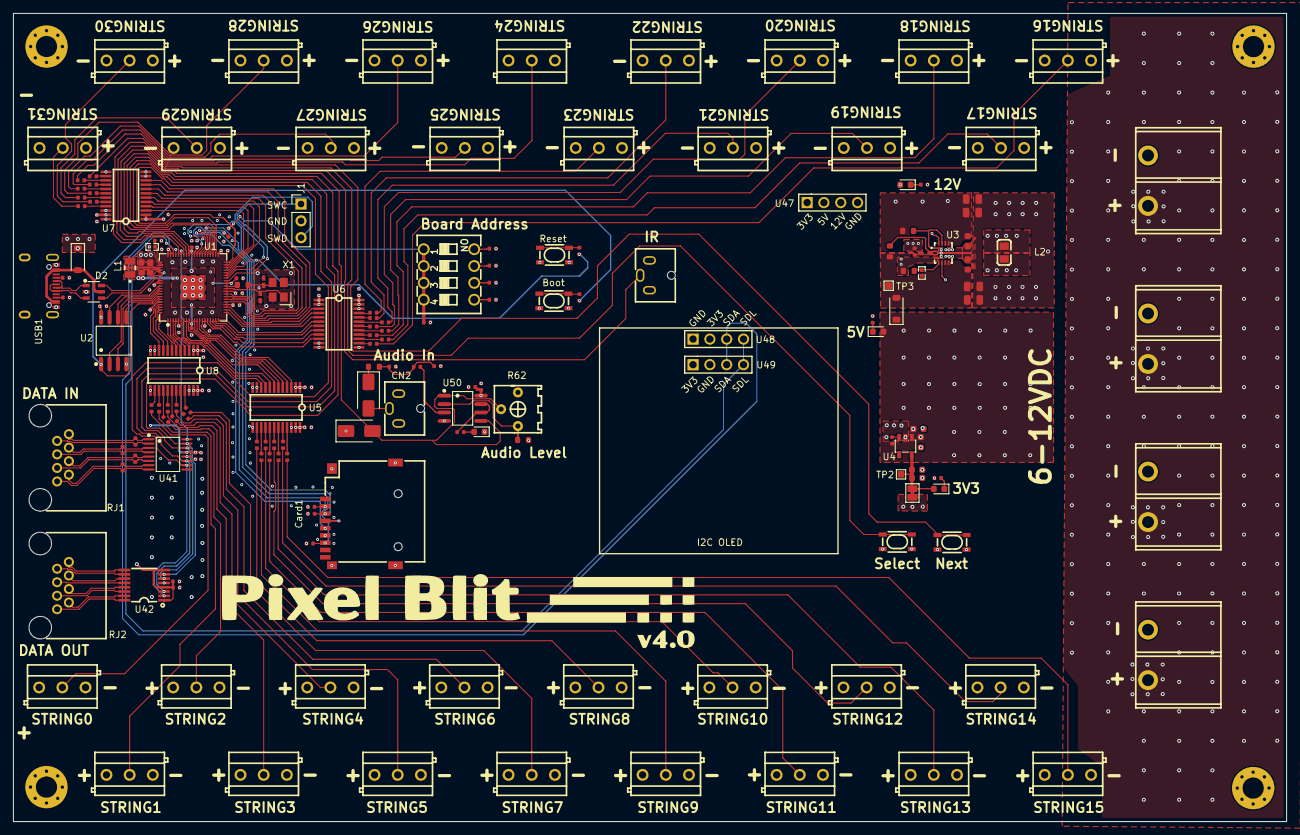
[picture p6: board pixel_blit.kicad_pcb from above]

Board: 4 copper layers, 192.2 x 122.0 mm, 192 parts (0 on the bottom side), 179 nets.

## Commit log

2025-09-24 Close to final, lots of cleanup, added back audio
    [communications.kicad_sch, peripherals.kicad_sch, pixel_blit.kicad_pcb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]
2025-11-04 Beef up power plane
    [pixel_blit.kicad_pcb]
2025-11-05 Library shuffle and Fabrication Toolkit micro adjustments
    [Power.kicad_sch, communications.kicad_sch, output.kicad_sch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]
2026-10-12 Next revision: drop the zone link fuses
2026-10-12 Next revision: confirm the Wi-Fi pins against the Pico SDK
2026-10-12 Next revision: drop the panel and 12V sense, add PSRAM, status LED and button
2026-10-12 Next revision: blown-fuse LED across each input fuse
2026-10-13 Bundle 3D models in the project, add board renders to the README
    The board's models were referenced through KICAD_3RD_PARTY,
    KICAD8_3RD_PARTY and KICAD9_3DMODEL_DIR, which KiCad 10 doesn't define, so
    most parts showed no 3D model. Copy all 38 into 3dmodels/ and point the
    board and the project footprint libraries at ${KIPRJMOD}/3dmodels.
    Also includes pending library and schematic edits, and ignores KiCad's
    .history/ folder.
2026-10-13 Next revision: PSRAM as a playback read-ahead buffer for high frame rates
2026-10-13 Next revision: 5 to 24V inputs, mixed voltages per zone, zone labelling
2026-10-13 Next revision: note the heat benefit of 24V
2026-10-13 Next revision: PTC Imax at least 2x the zone fuse rating
2026-10-13 Next revision: wide-input buck-boost for a regulated 5V data rail from 5 to 24V
